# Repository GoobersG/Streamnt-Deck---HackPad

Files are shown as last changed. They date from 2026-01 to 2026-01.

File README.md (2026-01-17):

# Hackpad

A custom DIY macro pad inspired by (but not at all) Stream Deck.

This project is a small hardware controller built around the **Seeed XIAO RP2040**, featuring:
- 6× Cherry MX mechanical switches  
- 1× EC11 rotary encoder  
- 1× 0.91" SSD1306 OLED display (I2C)  
- A fully custom PCB (KiCad)  
- A 3D-printed snug-fit case

Designed and built as a Hack Club hardware project.

---

## Hardware Overview

- **MCU:** Seeed Studio XIAO RP2040 (DIP)
- **Switches:** Cherry MX compatible (6 total)
- **Encoder:** EC11 rotary encoder
- **Display:** SSD1306 OLED, 0.91", 128×32, I2C (4-pin)
- **Power:** USB-C via XIAO
- **Enclosure:** 3D printed (top + bottom)

---

## Pin Mapping

### Switches
| Switch | Function | XIAO Pin |
|---|---|---|
| SW1 | Key 1 | GPIO26 |
| SW2 | Key 2 | GPIO2 |
| SW3 | Key 3 | GPIO1 |
| SW4 | Key 4 | GPIO27 |
| SW5 | Key 5 | GPIO3 |
| SW6 | Key 6 | GPIO4 |

### Rotary Encoder
| Signal | XIAO Pin |
|---|---|
| Encoder A | GPIO28 |
| Encoder B | GPIO29 |
| Encoder C | GND |

### OLED (SSD1306, I2C)
| Signal | XIAO Pin |
|---|---|
| SDA | GPIO5 |
| SCL | GPIO6 |
| VCC | 3V3 |
| GND | GND |

---

### PCB
- KiCad project files (`.kicad_sch`, `.kicad_pcb`, `.kicad_pro`)
- Gerbers and drill files for manufacturing
- PDF exports of schematic and PCB
- STEP file for enclosure design

## PCB Images
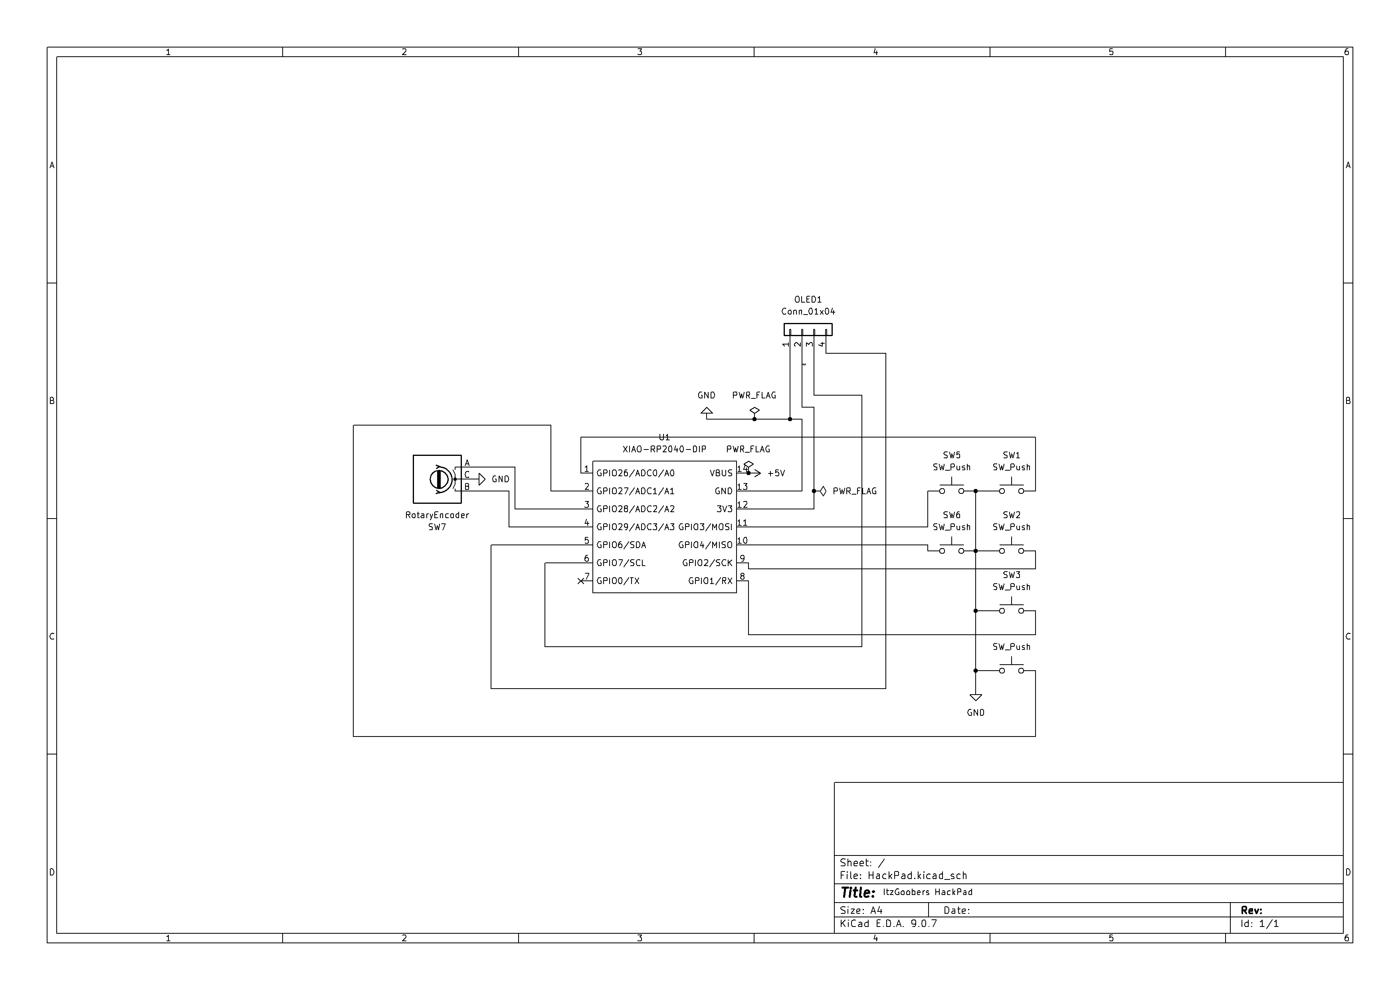
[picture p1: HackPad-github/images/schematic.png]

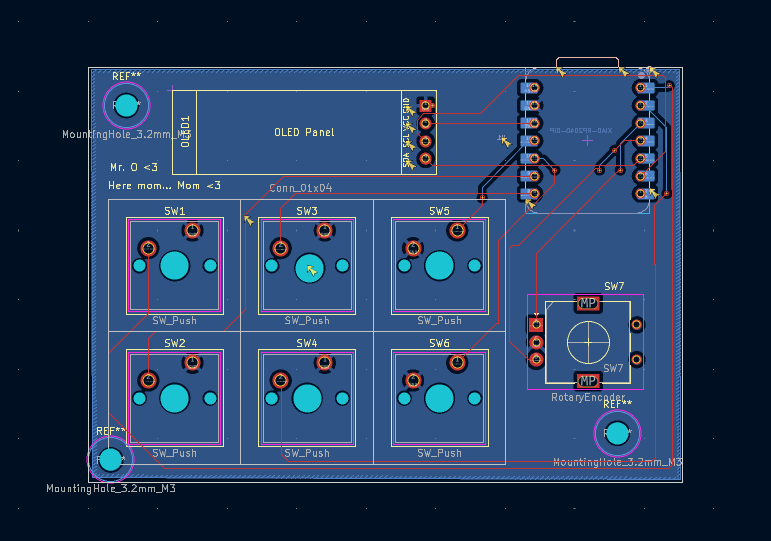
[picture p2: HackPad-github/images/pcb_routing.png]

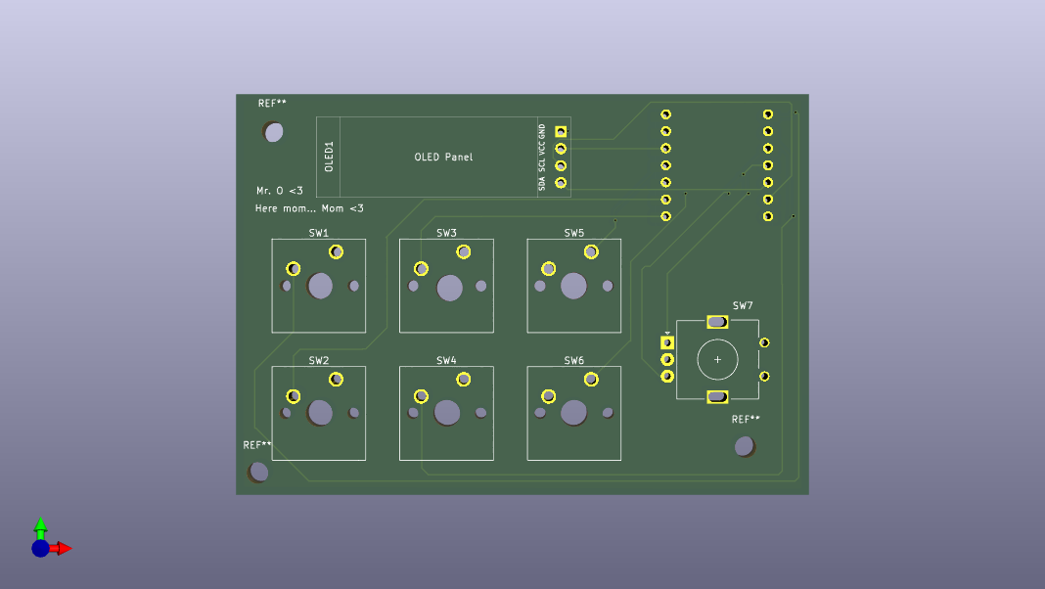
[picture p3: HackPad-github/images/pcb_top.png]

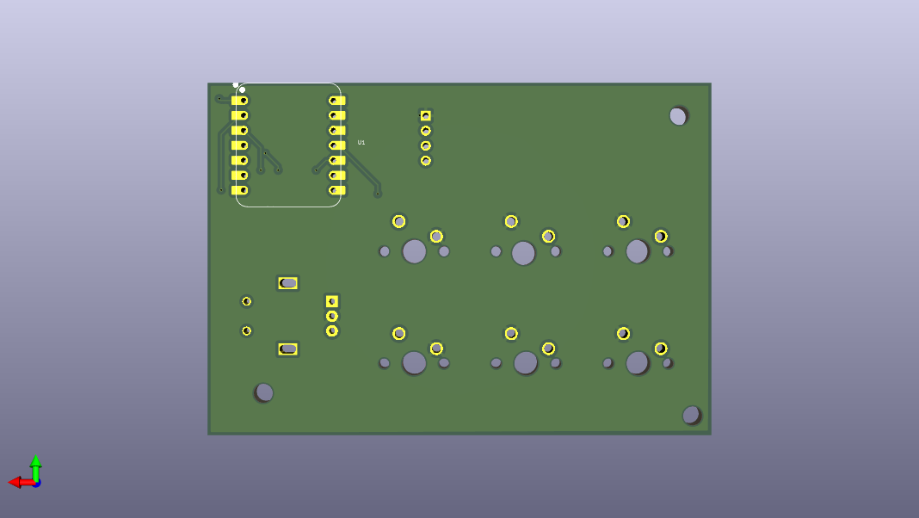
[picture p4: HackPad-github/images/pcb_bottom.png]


### Case
- Fusion 360 design file
- STL files for:
  - `case_top.stl`
  - `case_bottom.stl`
-STEP files for:
  - `case_bottom.step`
  - `case_top.step`
  - `hackpad_case_assembly.step`

---

## Case Design Notes

- 3 mm walls and bottom thickness
- Internal snup-fit using wall thickness
- PCB is fully supported without mounting holes
- Designed for FDM printing (PLA+ / PETG recommended)

## Case Images
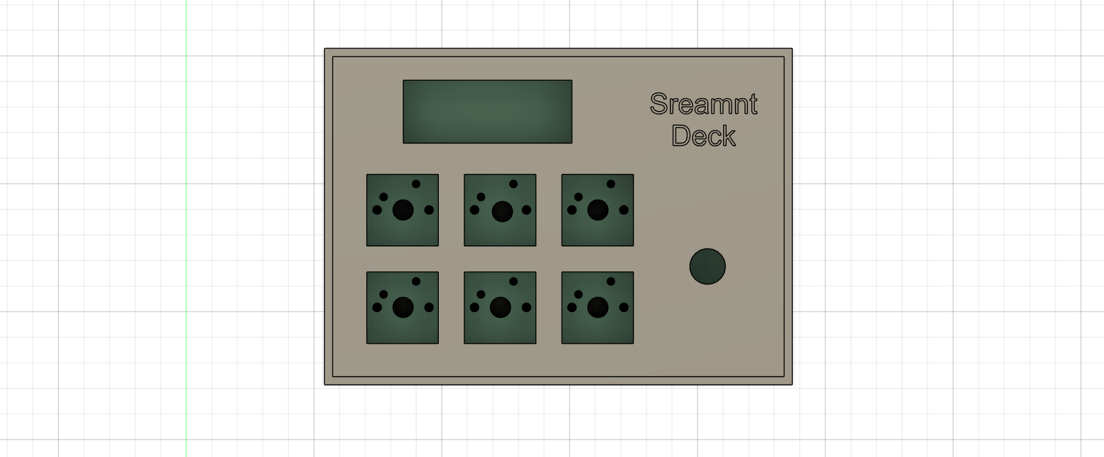
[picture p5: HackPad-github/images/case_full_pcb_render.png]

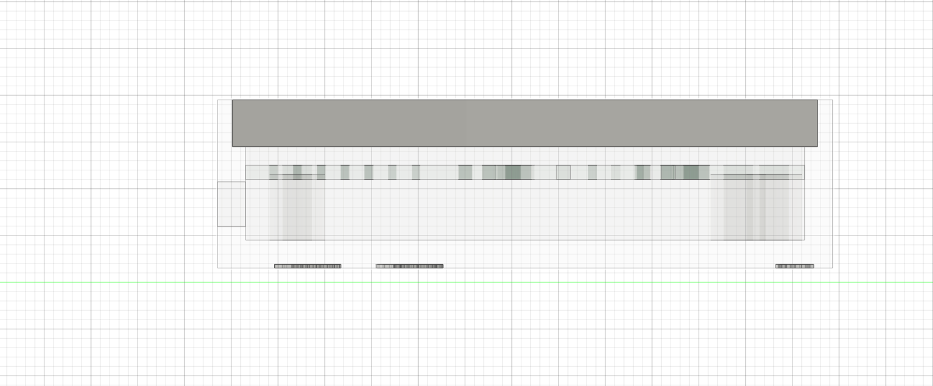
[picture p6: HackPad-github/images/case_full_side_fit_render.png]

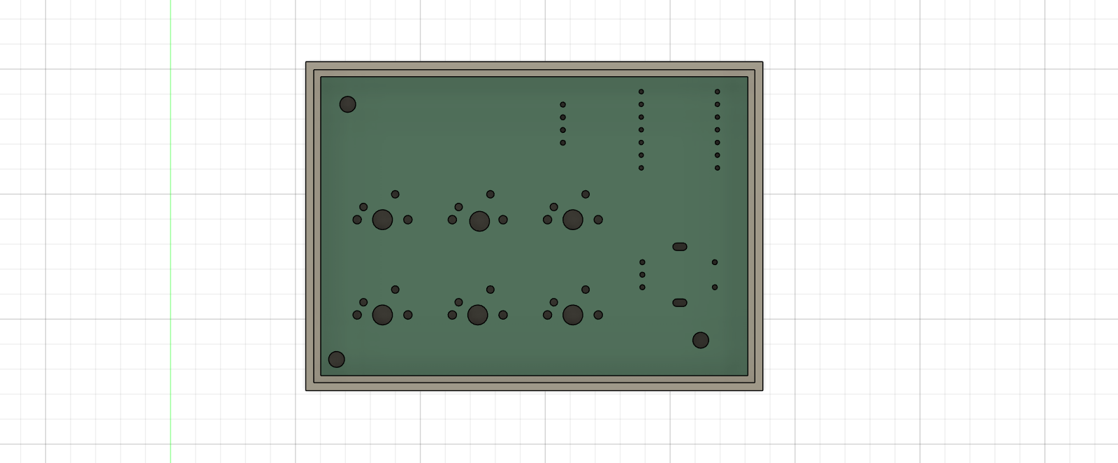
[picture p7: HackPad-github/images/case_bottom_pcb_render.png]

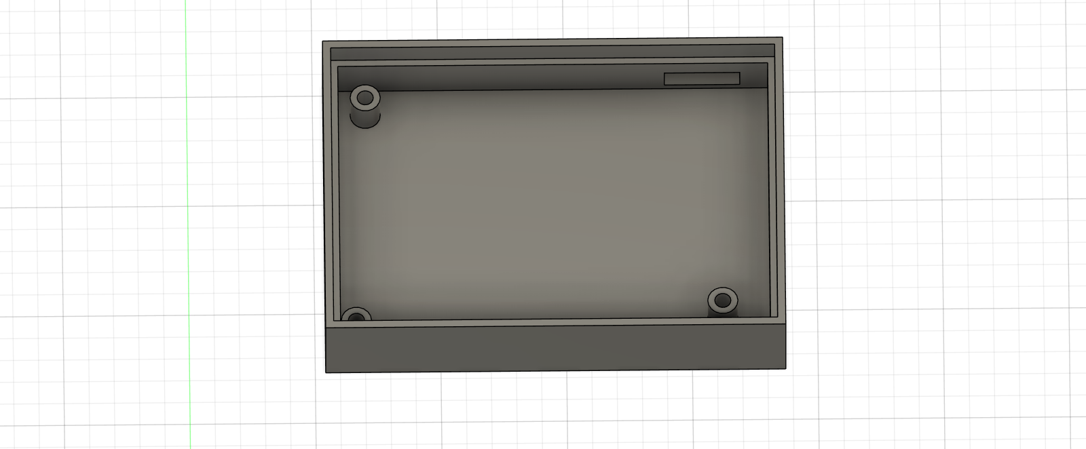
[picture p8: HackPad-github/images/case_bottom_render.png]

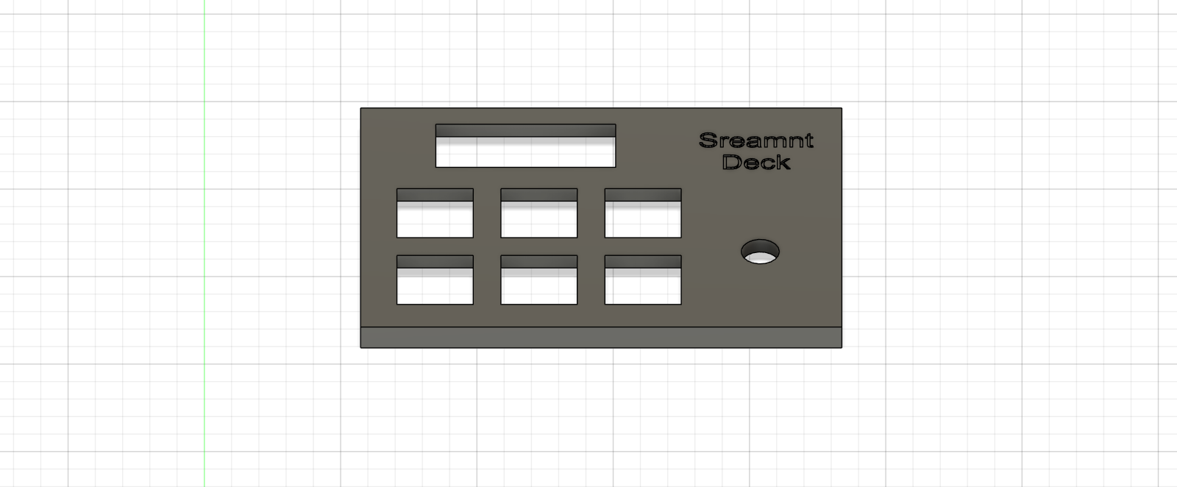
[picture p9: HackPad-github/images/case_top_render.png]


---

## Build Instructions (High Level)

1. Order PCB using the Gerbers in `hardware/kicad/fabrication/`
2. Solder:
   - Switches
   - Encoder
   - OLED header
3. Plug in XIAO RP2040
4. 3D print the case (STLs in `case/stl/`)
5. Assemble PCB into bottom case
6. Snap on top case
7. Flash firmware (see `firmware/`)

---

## Status

- Hardware: ✅ complete  
- PCB: ✅ routed and exported  
- Case: ✅ designed and printable  
- Firmware: Demo Ready

---

## License

MIT License — feel free to learn from, modify, and build on this project.

---

**STREAMN’T DECK**

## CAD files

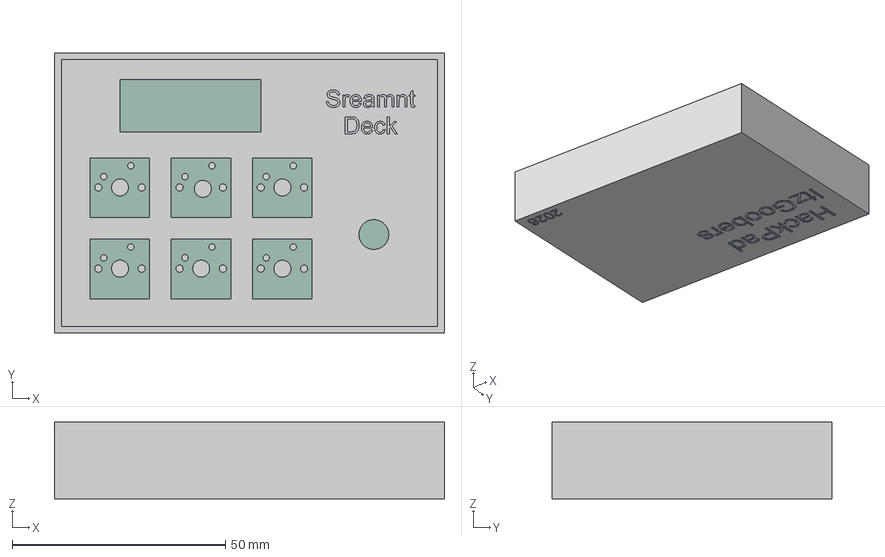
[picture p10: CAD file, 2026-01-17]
HackPad-github/case/step/hackpad_case_assembly.step
91.5 x 65.8 x 18.0 mm
HackPad_PCB

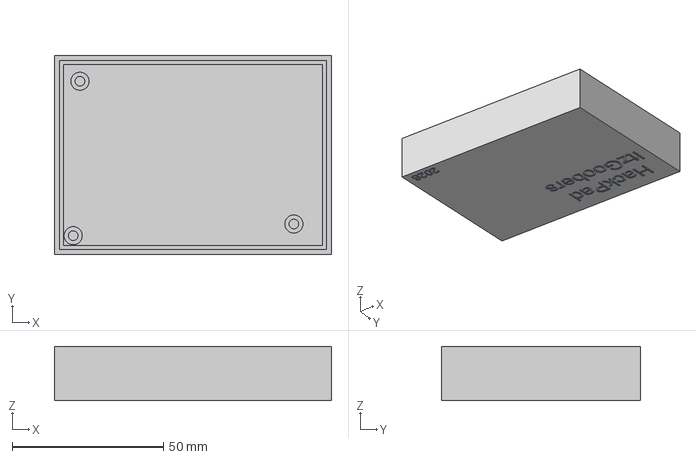
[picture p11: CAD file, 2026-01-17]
HackPad-github/case/step/case_bottom.step
91.5 x 65.8 x 18.0 mm

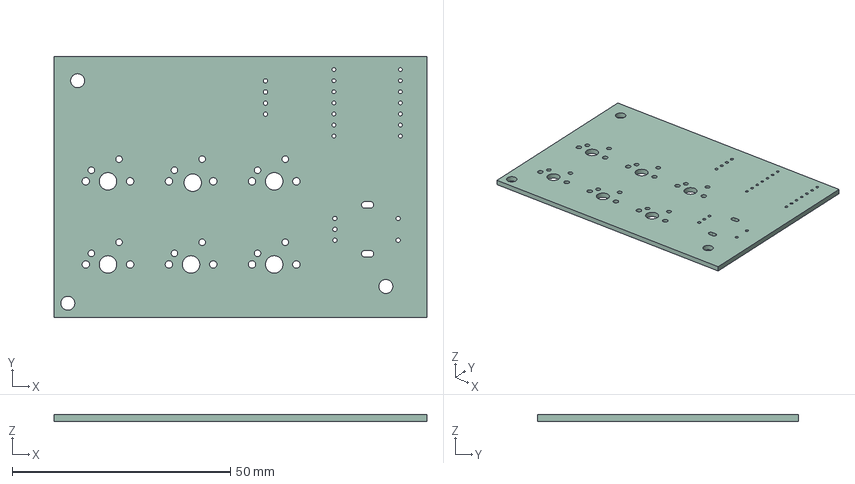
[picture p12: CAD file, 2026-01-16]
HackPad-github/hardware/kicad/exports/HackPad.step
85.5 x 59.8 x 1.51 mm

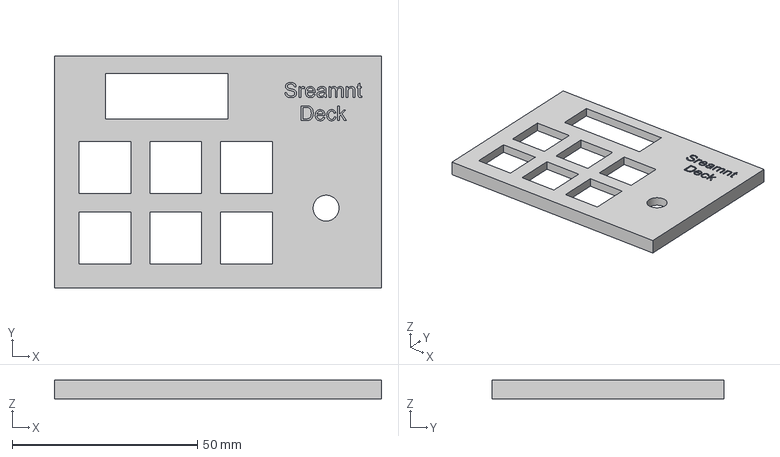
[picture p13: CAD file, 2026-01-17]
HackPad-github/case/step/case_top.step
88.3 x 62.6 x 5.00 mm

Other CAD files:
HackPad-github/case/stl/Case_Base.stl
HackPad-github/case/fusion/case.f3d
HackPad-github/case/stl/Case_Top.stl

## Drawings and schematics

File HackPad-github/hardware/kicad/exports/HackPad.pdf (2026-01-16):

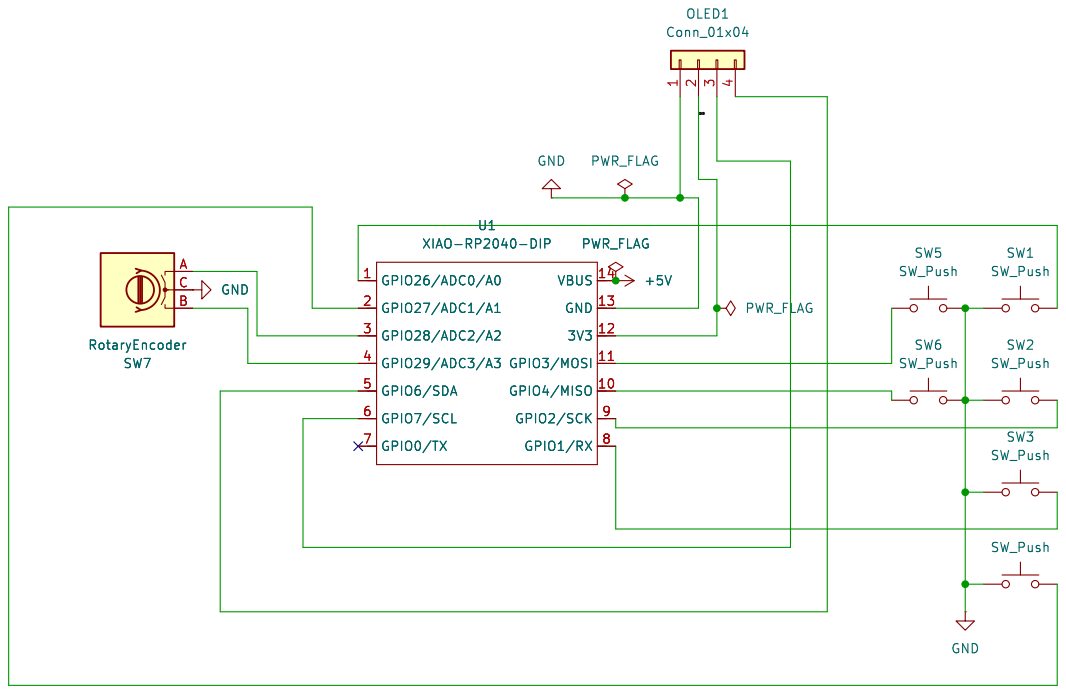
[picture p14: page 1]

Id: 1/1 Title: File: HackPad.kicad_sch Sheet: /

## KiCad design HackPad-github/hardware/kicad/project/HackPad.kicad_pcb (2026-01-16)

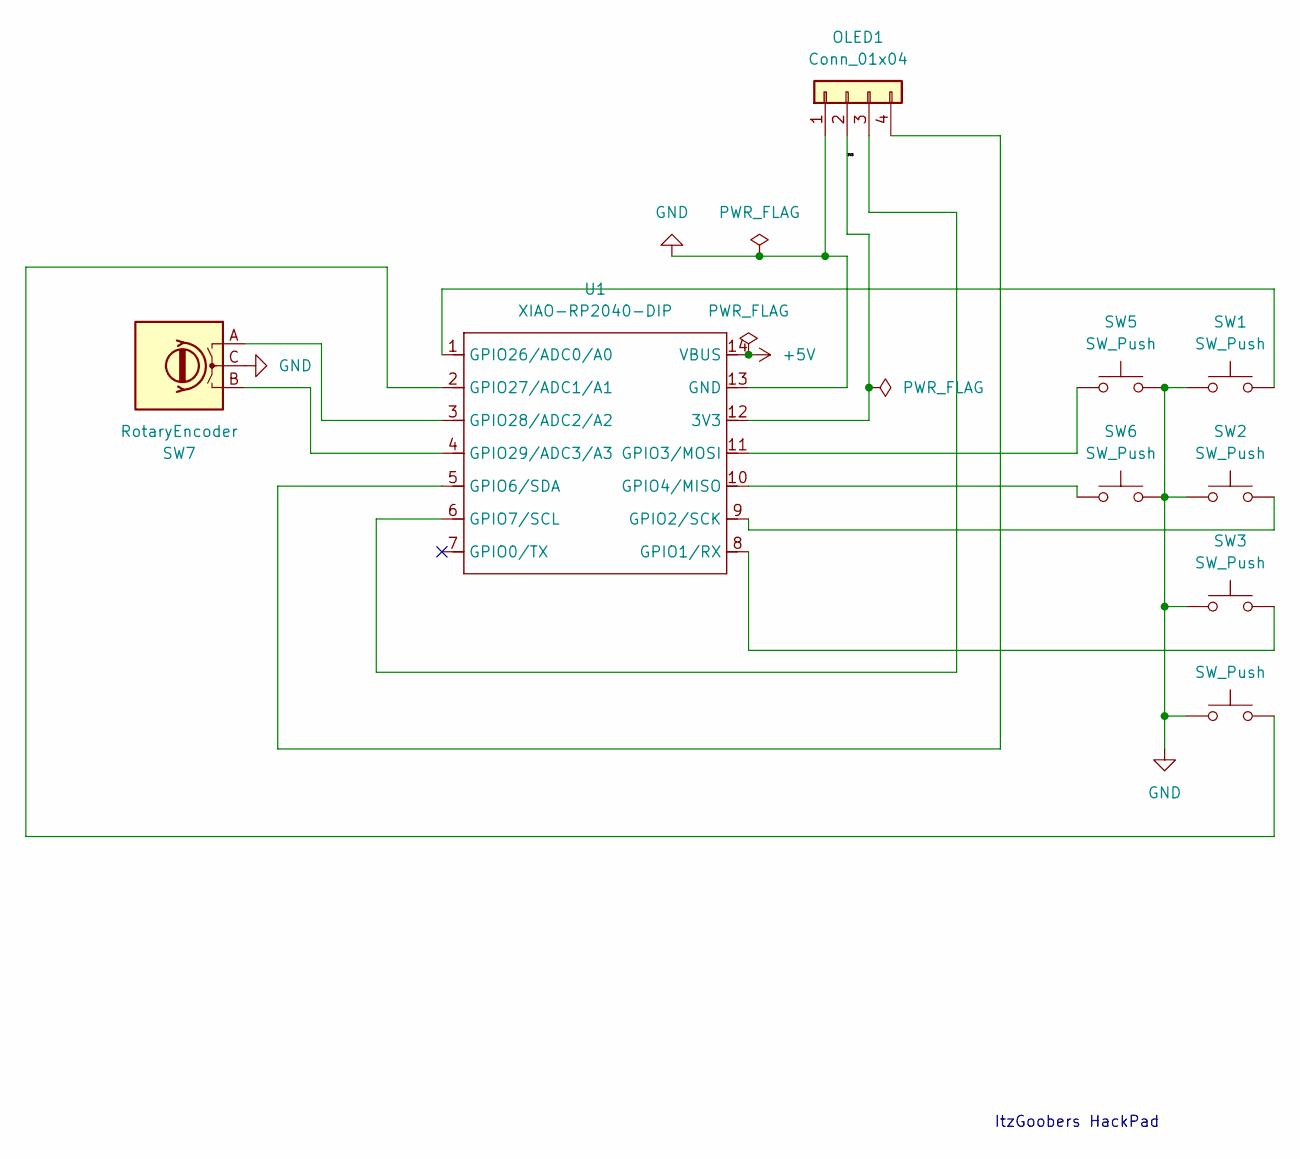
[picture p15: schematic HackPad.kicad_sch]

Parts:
OLED1: Conn_01x04; SSD1306-0.91-OLED-4pin-128x32
SW1, SW2, SW3, SW4, SW5, SW6: SW_Push; SW_Cherry_MX_1.00u_PCB
SW7: RotaryEncoder; RotaryEncoder_Alps_EC11E_Vertical_H20mm
U1: XIAO-RP2040-DIP

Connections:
+5V: U1.14 (VBUS)
/3V3: OLED1.2 (VCC), U1.12 (3V3)
GND: OLED1.1 (GND), SW1.1, SW2.1, SW3.1, SW4.1, SW5.2, SW6.2, SW7.C, U1.13 (GND)
unnamed: OLED1.3 (SCL), U1.6 (GPIO7/SCL)
unnamed: OLED1.4 (SDA), U1.5 (GPIO6/SDA)
unnamed: SW3.2, U1.8 (GPIO1/RX)
unnamed: SW2.2, U1.9 (GPIO2/SCK)
unnamed: SW5.1, U1.11 (GPIO3/MOSI)
unnamed: SW6.1, U1.10 (GPIO4/MISO)
unnamed: SW1.2, U1.1 (GPIO26/ADC0/A0)
unnamed: SW4.2, U1.2 (GPIO27/ADC1/A1)
unnamed: SW7.A, U1.3 (GPIO28/ADC2/A2)
unnamed: SW7.B, U1.4 (GPIO29/ADC3/A3)

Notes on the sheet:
ItzGoobers HackPad

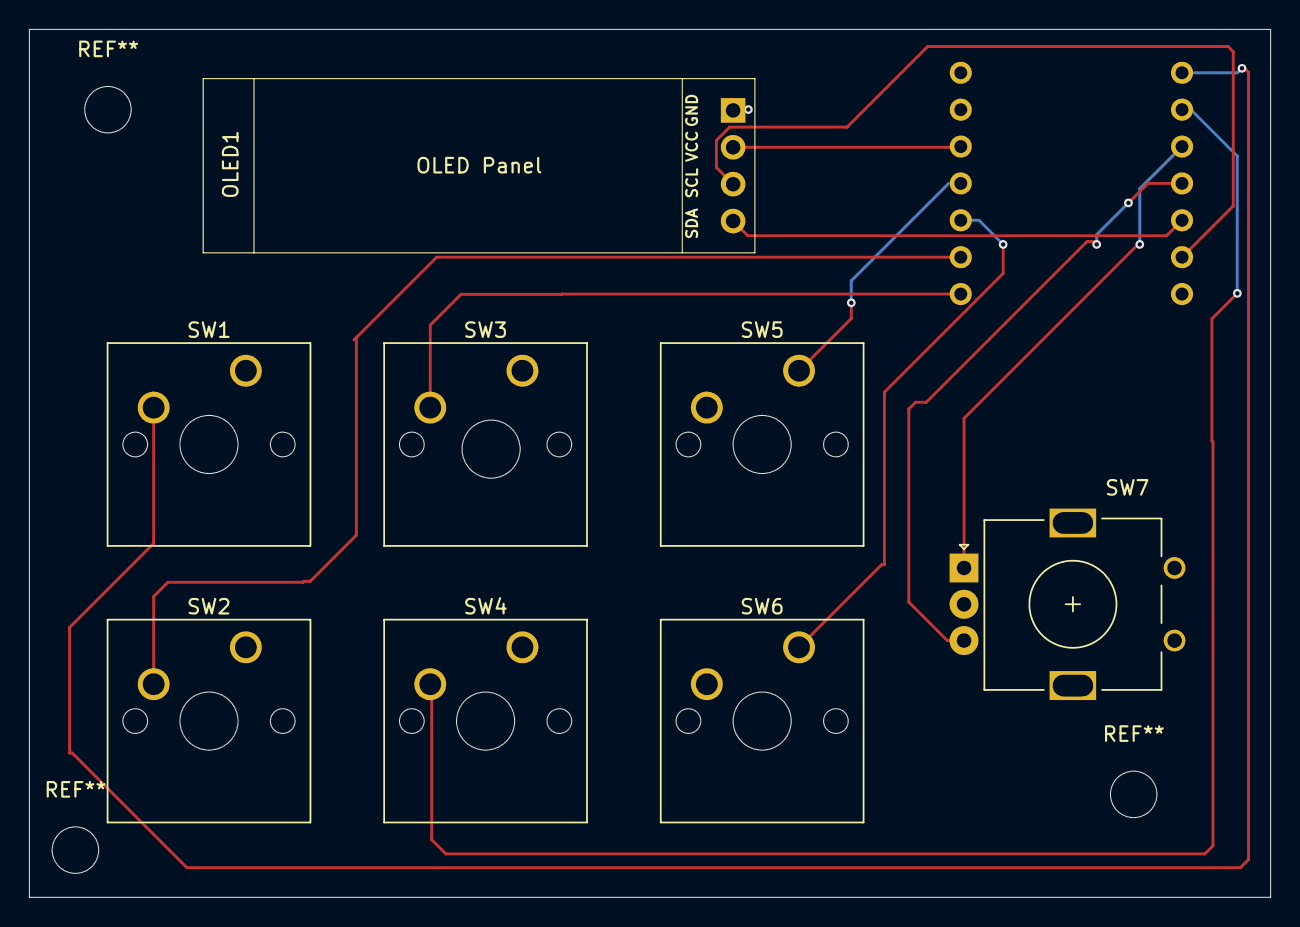
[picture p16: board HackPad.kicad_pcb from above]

Board: 2 copper layers, 85.5 x 59.8 mm, 9 parts (1 on the bottom side), 12 nets.

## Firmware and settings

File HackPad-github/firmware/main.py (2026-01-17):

import board

from kmk.kmk_keyboard import KMKKeyboard
from kmk.scanners.keypad import KeysScanner
from kmk.keys import KC
from kmk.modules.encoder import EncoderHandler

keyboard = KMKKeyboard()

# --- Buttons ---
# [SW1, SW3, SW5]
# [SW2, SW4, SW6]
PINS = [
    board.GP26,  # SW1
    board.GP1,   # SW3
    board.GP3,   # SW5

    board.GP2,   # SW2
    board.GP27,  # SW4
    board.GP4,   # SW6
]


keyboard.matrix = KeysScanner(
    pins=PINS,
    value_when_pressed=False,
)

keyboard.keymap = [
    [
        KC.A, KC.B, KC.C,
        KC.D, KC.E, KC.F,
    ]
]

# --- Encoder ---
# EC11: A and B to GPIOs, C to GND
encoder = EncoderHandler()
keyboard.modules.append(encoder)

# Encoder pins: (A, B)
encoder.pins = ((board.GP28, board.GP29),)

# What rotation does: (CCW, CW)
# Pick one:
# encoder.map = (((KC.VOLD, KC.VOLU),),)      # Volume
encoder.map = (((KC.LEFT, KC.RIGHT),),)       # Arrows

if __name__ == '__main__':
    keyboard.go()

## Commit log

2026-01-17 Include STEP files for case design
    Added STEP files for case components.
2026-01-17 Add PCB and case images to README
    Added images for PCB and case to the README.
2026-01-17 Update case image in README.md
